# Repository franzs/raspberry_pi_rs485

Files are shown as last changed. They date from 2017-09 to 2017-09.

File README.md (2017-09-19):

# RS485 shield for Raspberry Pi 2/3

This Raspberry Pi RS485 module was heavily inspired by an article
from the excellent german c't magazin:

[Unter Strom - Stromverbrauch analysieren mit Raspi und Smart Meter](https://www.heise.de/ct/ausgabe/2017-17-Stromverbrauch-analysieren-mit-Raspi-und-Smart-Meter-3787264.html)

In addition to the schematic published a level shifter was added
for the RXD input.

This shield was build around the [MAX485 module](http://www.chinalctech.com/index.php?_m=mod_product&_a=view&p_id=811) from LC Electronics.

There is an
[AISLER project](https://aisler.net/franz/raspberry-pi-rs485-module/main-pcb)
if you like to order a PCB.

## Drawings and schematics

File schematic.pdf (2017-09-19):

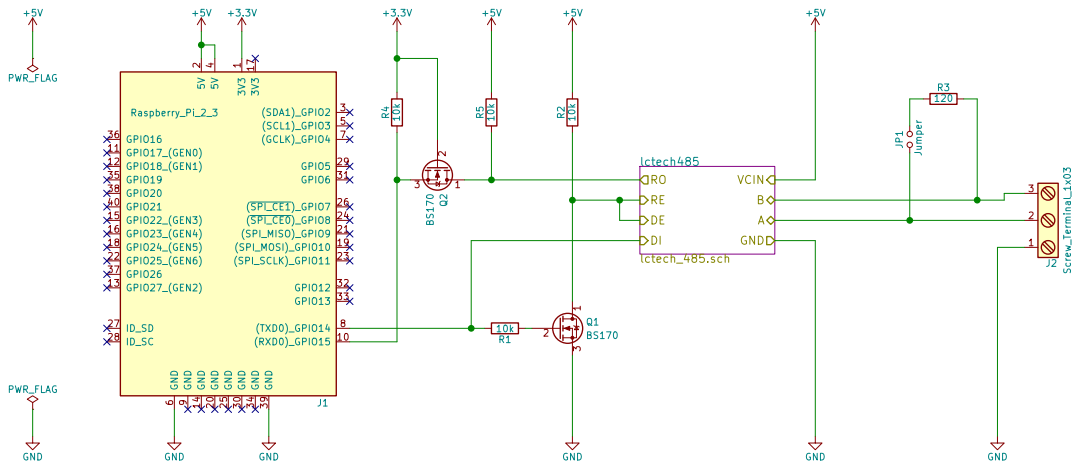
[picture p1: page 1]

File: raspberry pi rs 485.sch Sheet: / Franz Schwartau 3V3

Id: 1/2 Title: Raspberry Pi RS485 Interface

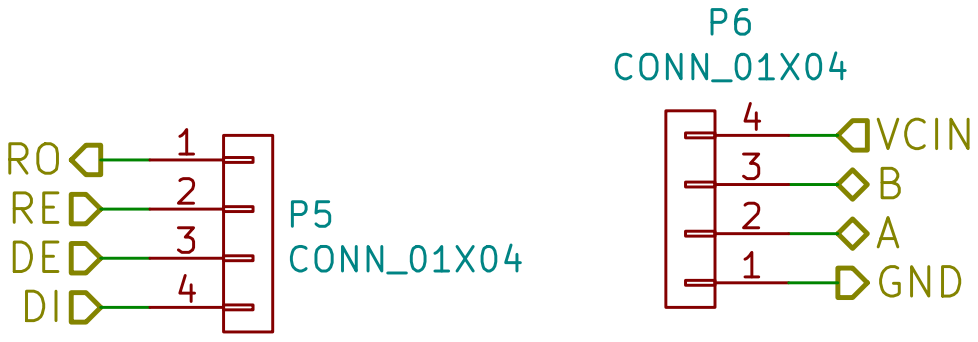
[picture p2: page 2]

Raspberry Pi / Arduino UART to RS485
Implements half-duplex with TX latched RE/DE
Size resistor values R1, R3, and R7 appropriately for your LED choices.

File: lctech_485.sch Sheet: /lctech485/ Bryan Varner

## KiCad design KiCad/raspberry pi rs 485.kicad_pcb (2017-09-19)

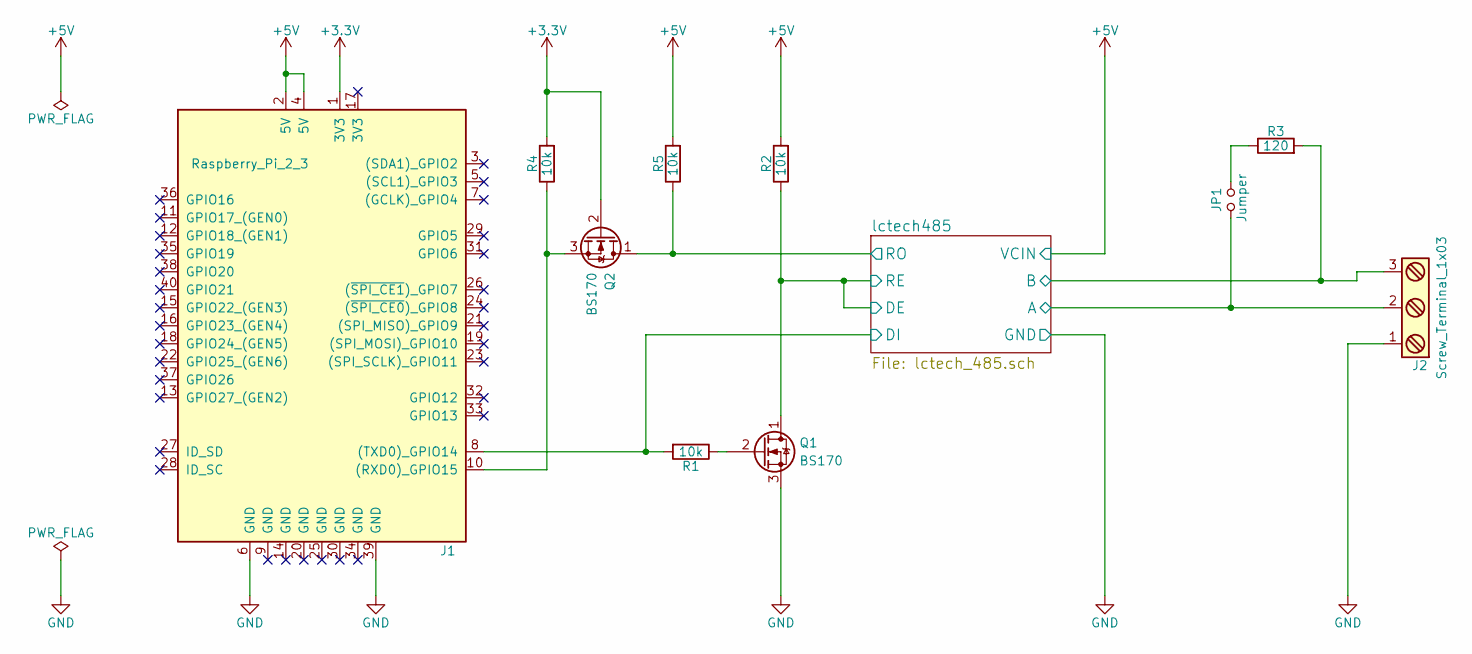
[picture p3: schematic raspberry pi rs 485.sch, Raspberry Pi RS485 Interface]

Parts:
J1: Raspberry_Pi_2_3; Pin_Header_Straight_2x20_Pitch2.54mm
J2: Screw_Terminal_1x03; bornier3
JP1: Jumper; Socket_Strip_Straight_2x01_Pitch2.54mm
Q1, Q2: BS170; TO-92_Molded_Wide_Oval
R1, R2, R4, R5: 10k; R_Axial_DIN0204_L3.6mm_D1.6mm_P7.62mm_Horizontal
R3: 120; R_Axial_DIN0204_L3.6mm_D1.6mm_P7.62mm_Horizontal

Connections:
+3V3: J1.1 (3V3), Q2.2 (G), R4.2
+5V: J1.2 (5V), J1.4 (5V), R2.2, R5.2; also elsewhere on the board
/lctech485/A: J2.2, JP1.1; also elsewhere on the board
/lctech485/B: J2.3, R3.2; also elsewhere on the board
/lctech485/DE: Q1.1 (D), R2.1; also elsewhere on the board
/lctech485/DI: J1.8 ((TXD0)_GPIO14), R1.2; also elsewhere on the board
/lctech485/RO: Q2.1 (D), R5.1; also elsewhere on the board
GND: J1.6 (GND), J1.39 (GND), J2.1, Q1.3 (S); also elsewhere on the board
unnamed: J1.10 ((RXD0)_GPIO15), Q2.3 (S), R4.1
unnamed: JP1.2, R3.1
unnamed: Q1.2 (G), R1.1

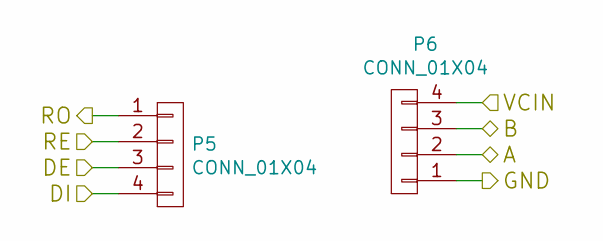
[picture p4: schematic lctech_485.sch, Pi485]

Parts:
P5, P6: CONN_01X04; Socket_Strip_Straight_1x04_Pitch2.54mm

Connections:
+5V: P6.4; also elsewhere on the board
/lctech485/A: P6.2; also elsewhere on the board
/lctech485/B: P6.3; also elsewhere on the board
/lctech485/DE: P5.2, P5.3; also elsewhere on the board
/lctech485/DI: P5.4; also elsewhere on the board
/lctech485/RO: P5.1; also elsewhere on the board
GND: P6.1; also elsewhere on the board

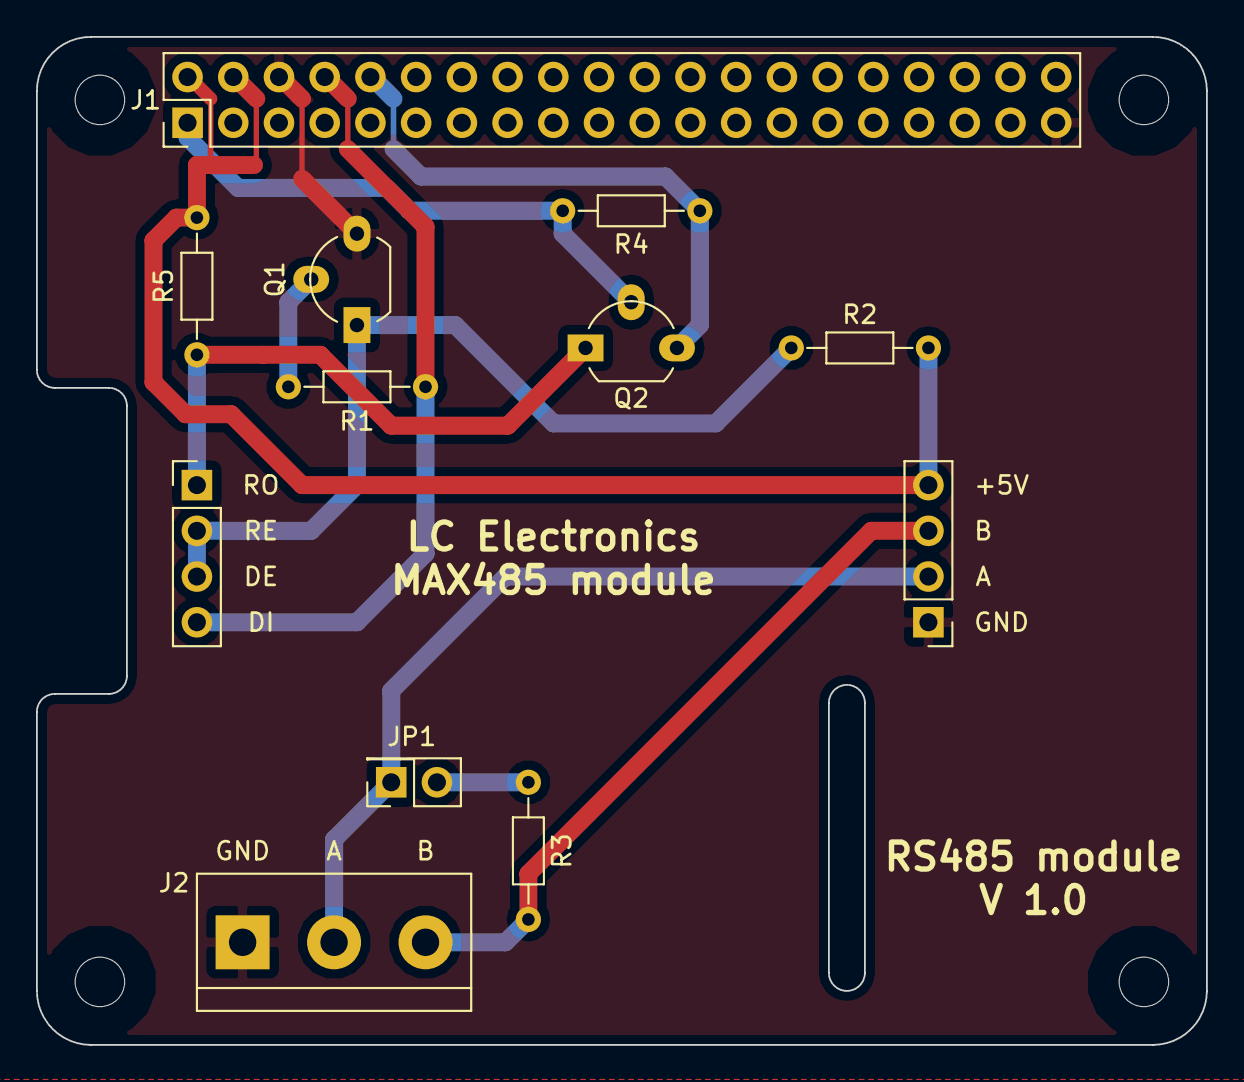
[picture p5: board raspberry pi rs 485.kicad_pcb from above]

Board: 2 copper layers, 65.0 x 56.0 mm, 12 parts (0 on the bottom side), 11 nets.

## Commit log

2017-09-19 Add KiCad files.
    [lctech_485.sch, raspberry pi rs 485.kicad_pcb, raspberry pi rs 485.sch]
2017-09-19 Add PDF of schematic.
